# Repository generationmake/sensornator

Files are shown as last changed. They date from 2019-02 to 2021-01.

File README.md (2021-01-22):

# Sensornator
Board with ESP32 in the Arduino Uno form factor

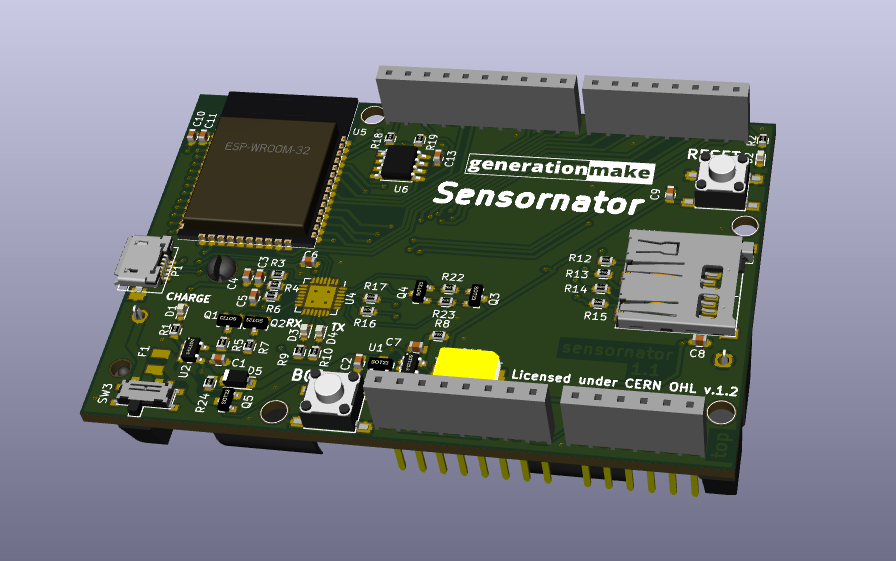
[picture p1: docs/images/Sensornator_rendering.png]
Sensornator rendering


## PCB

### Top

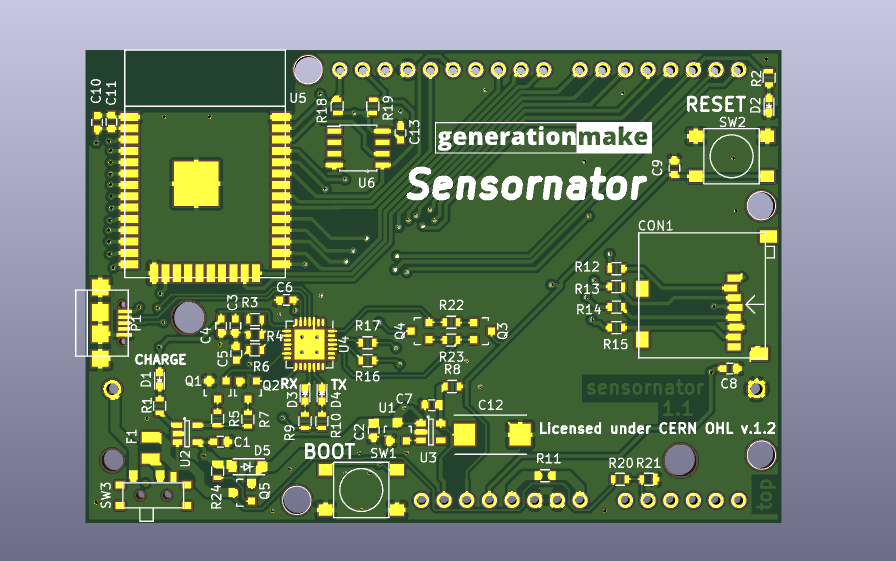
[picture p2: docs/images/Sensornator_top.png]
Sensornator PCB top


### Bottom

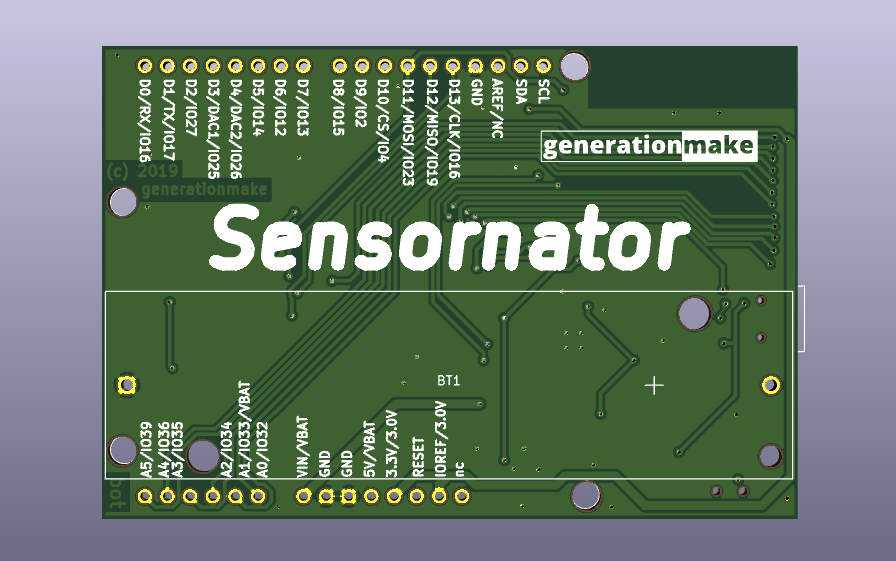
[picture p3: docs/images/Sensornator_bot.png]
Sensornator PCB bot


## License

This hardware is licensed under the CERN OHL v. 1.2

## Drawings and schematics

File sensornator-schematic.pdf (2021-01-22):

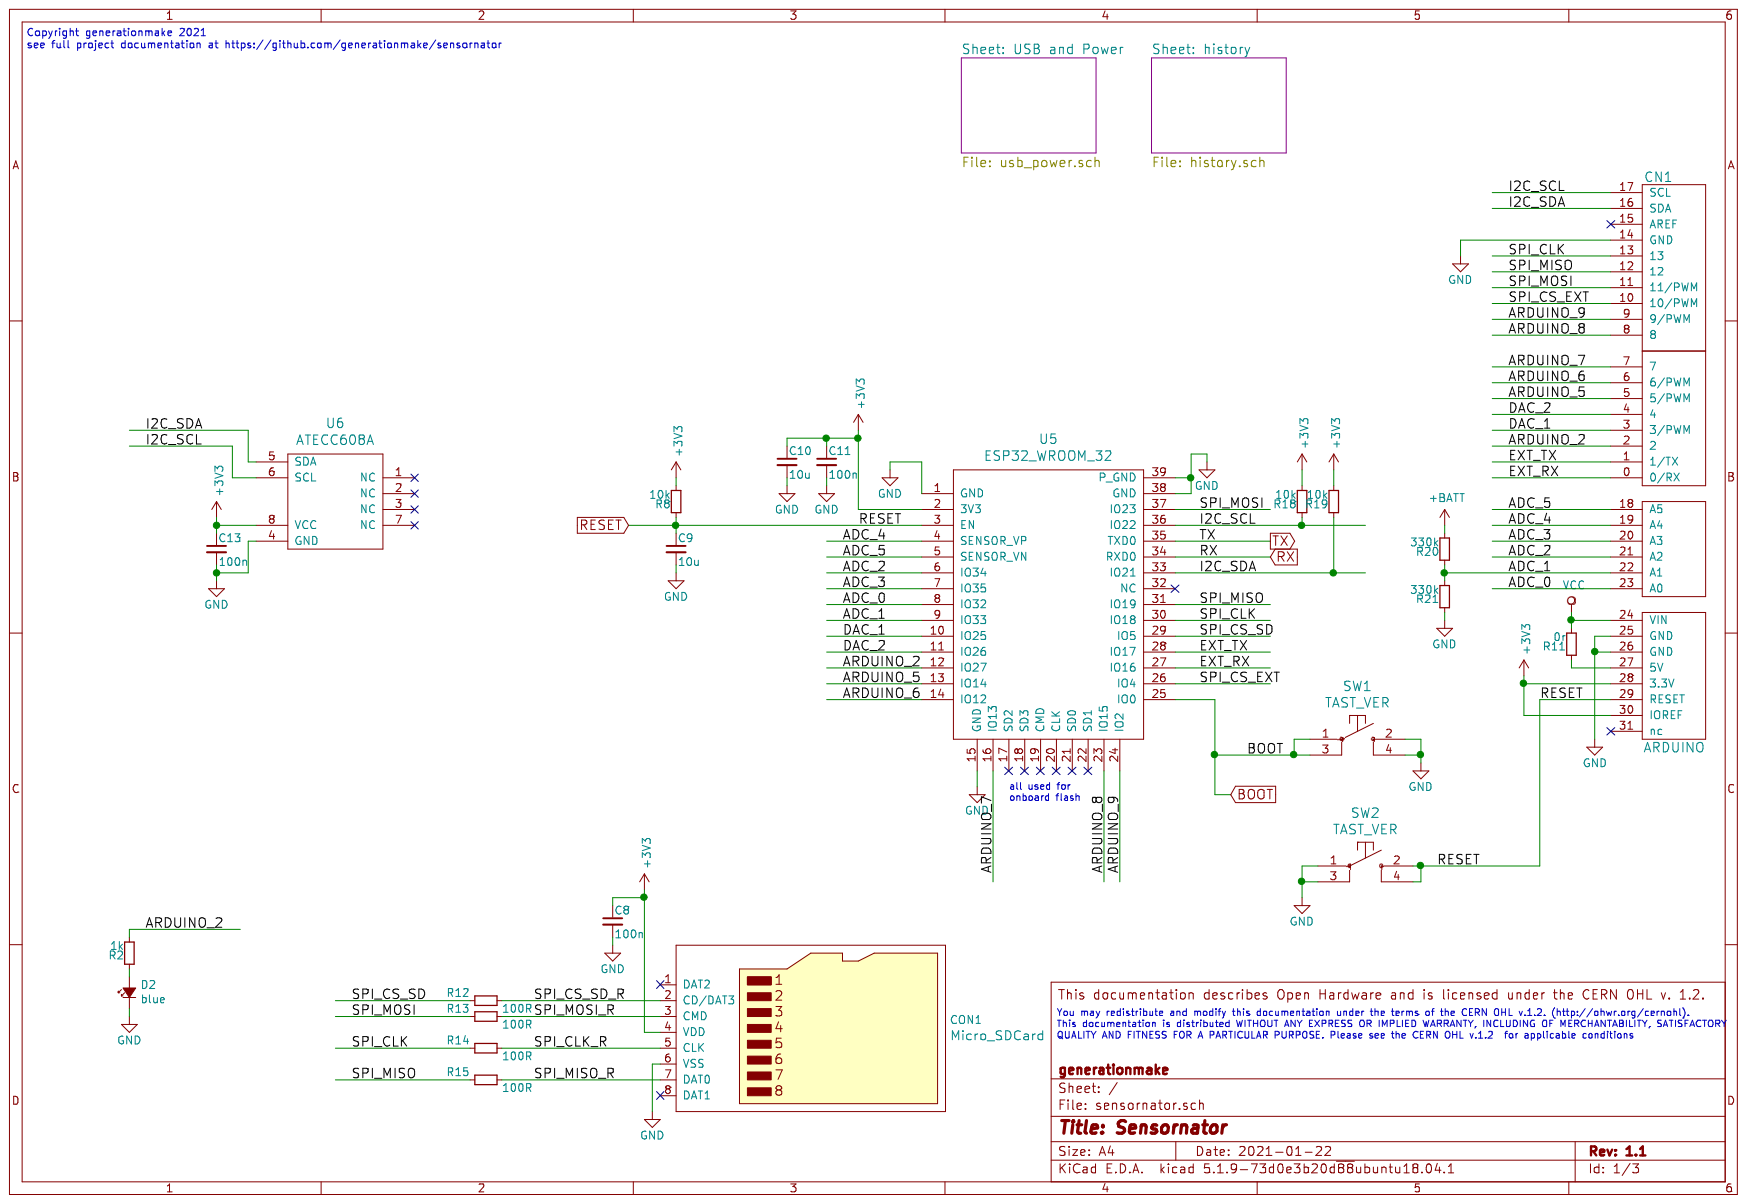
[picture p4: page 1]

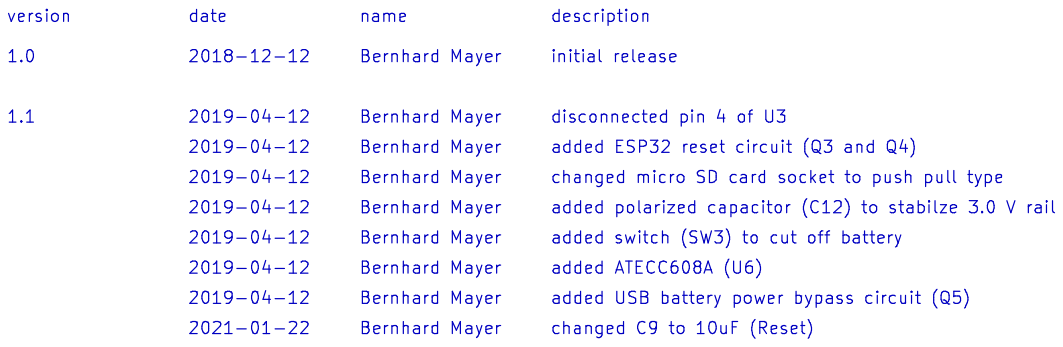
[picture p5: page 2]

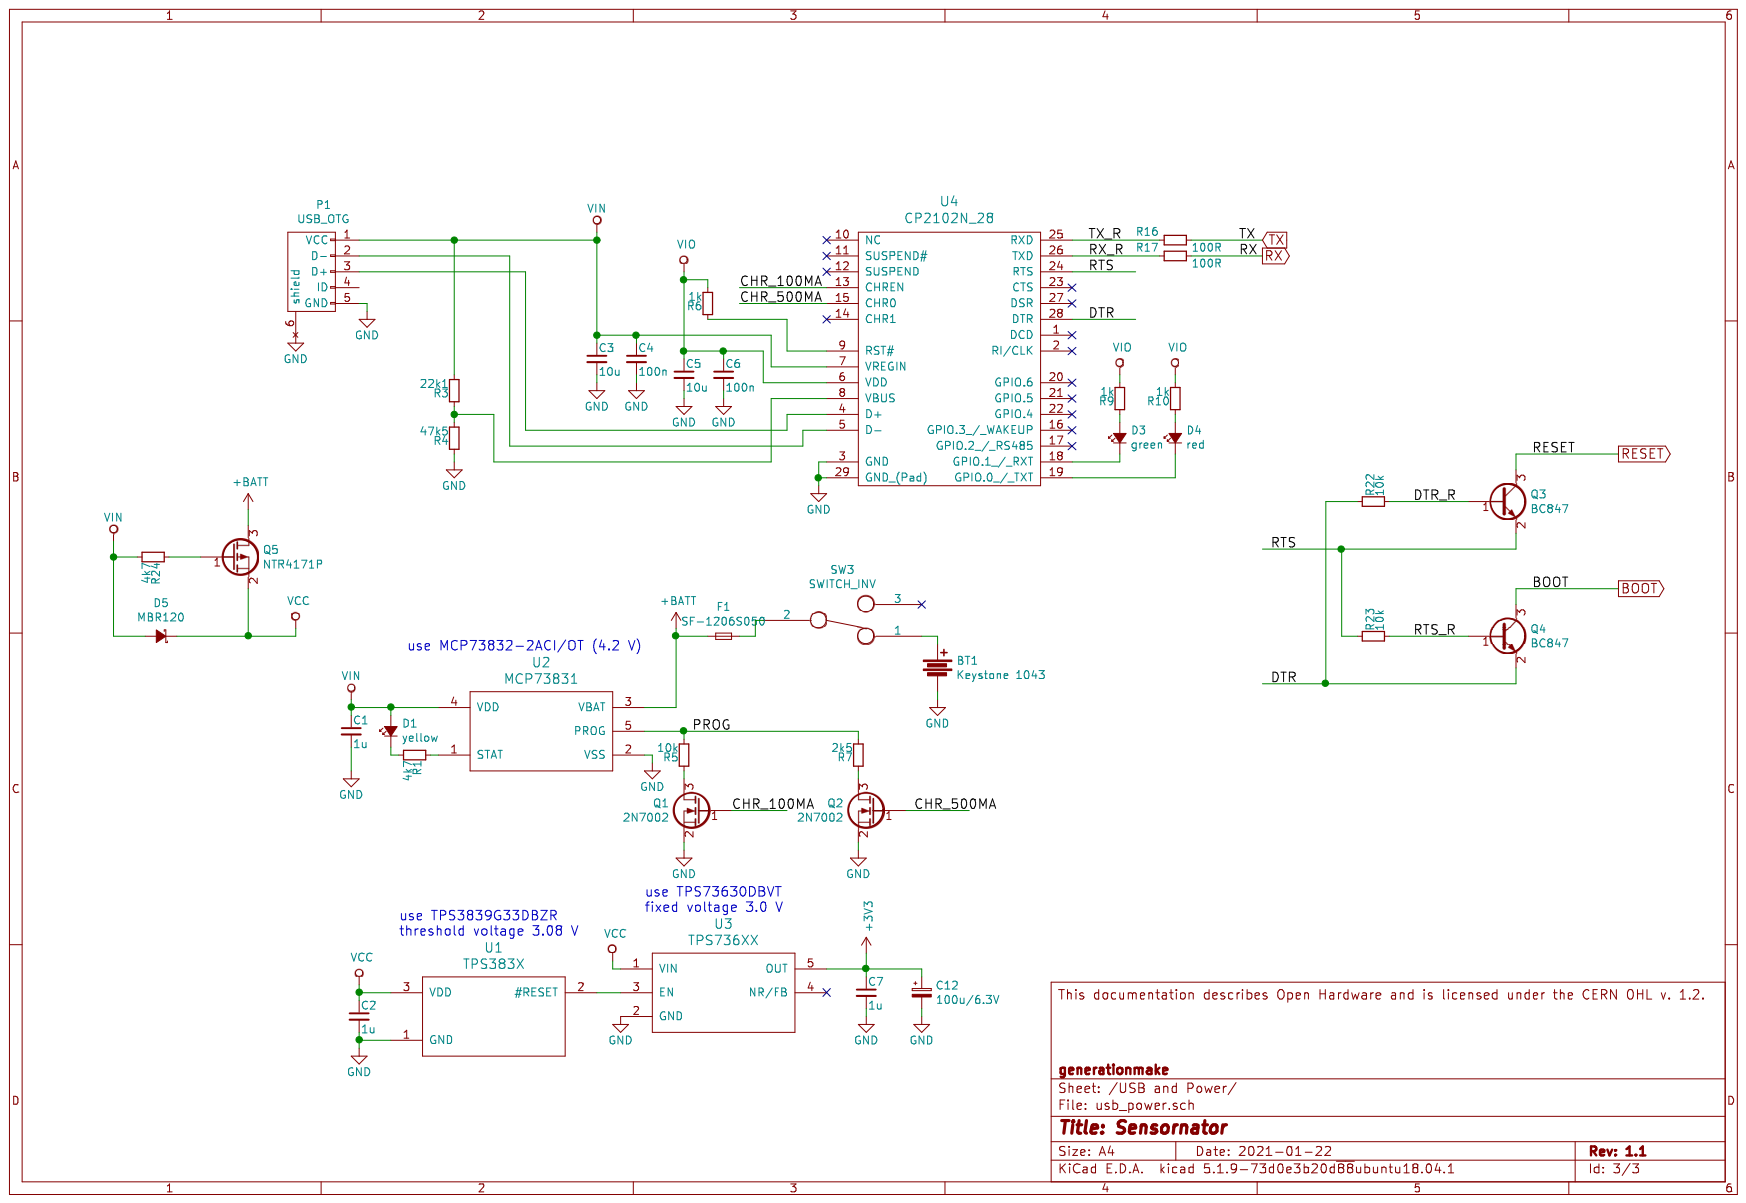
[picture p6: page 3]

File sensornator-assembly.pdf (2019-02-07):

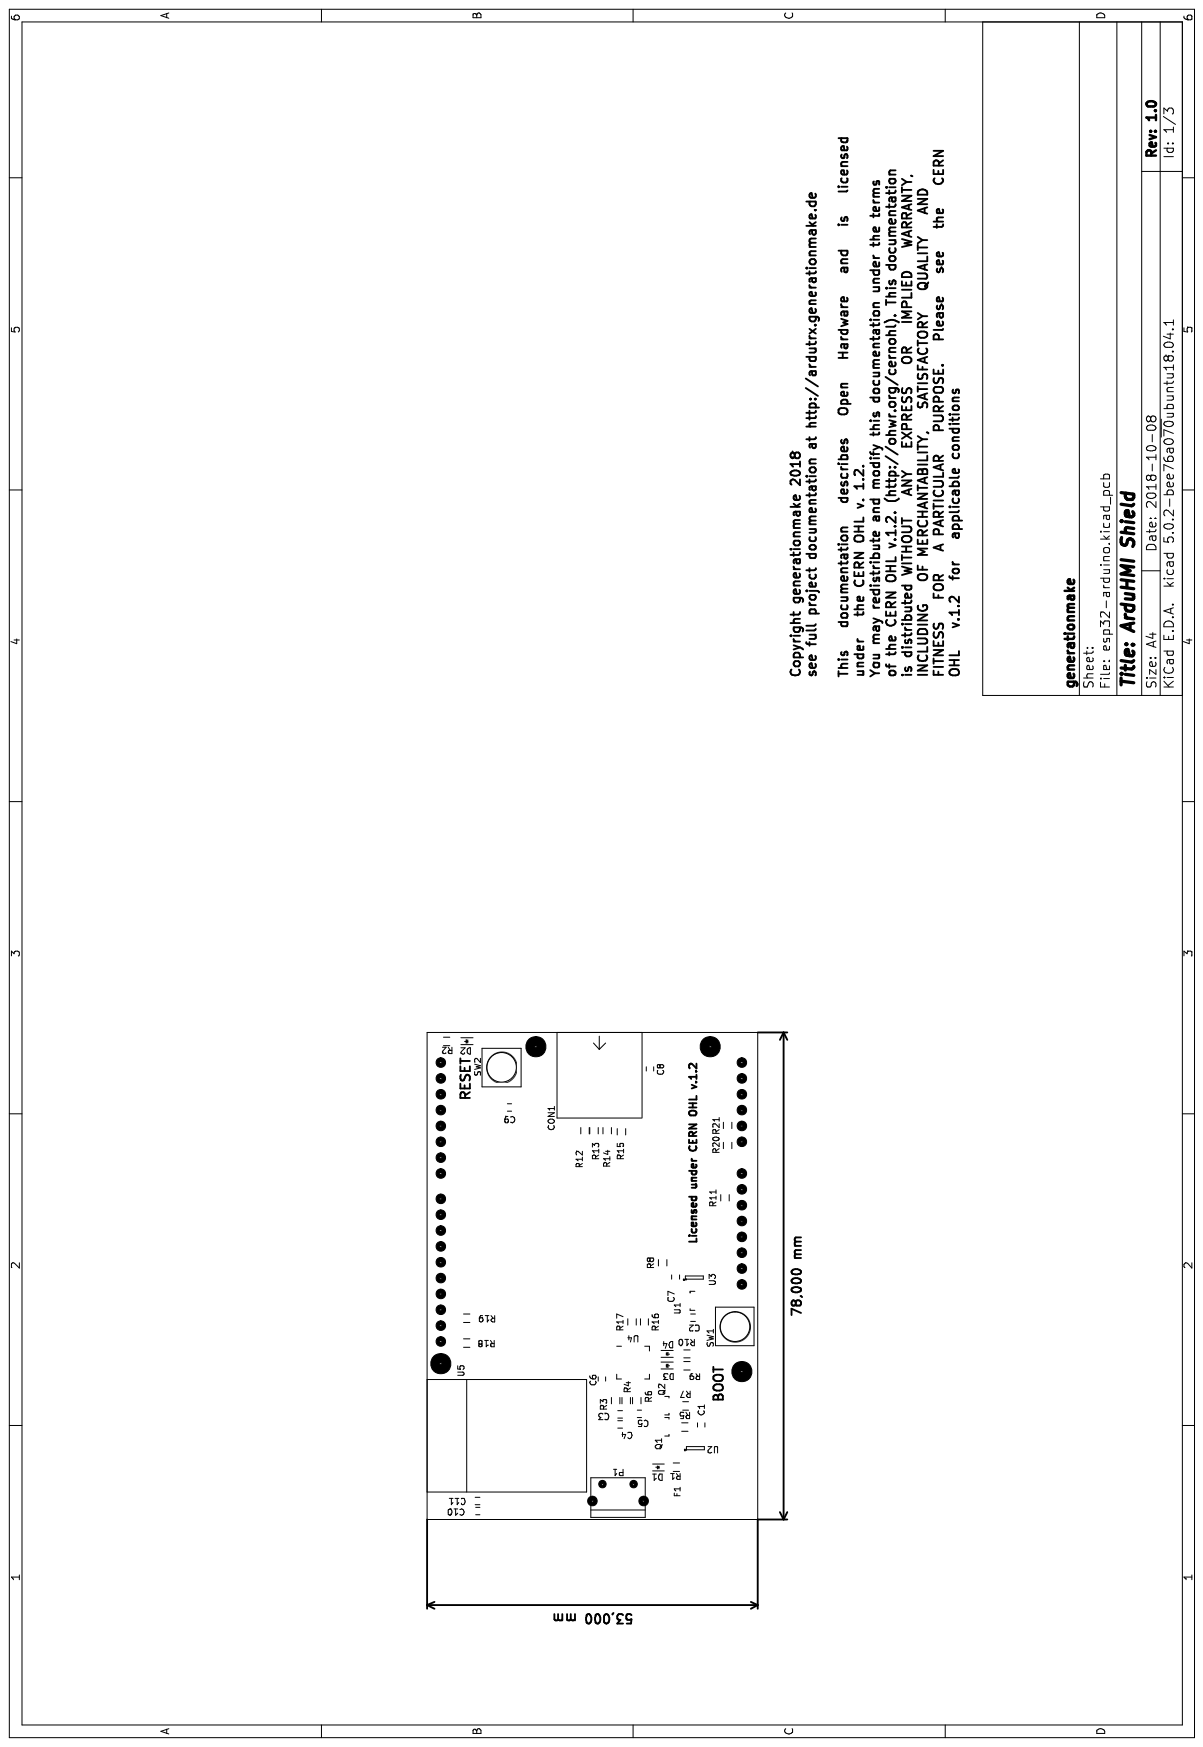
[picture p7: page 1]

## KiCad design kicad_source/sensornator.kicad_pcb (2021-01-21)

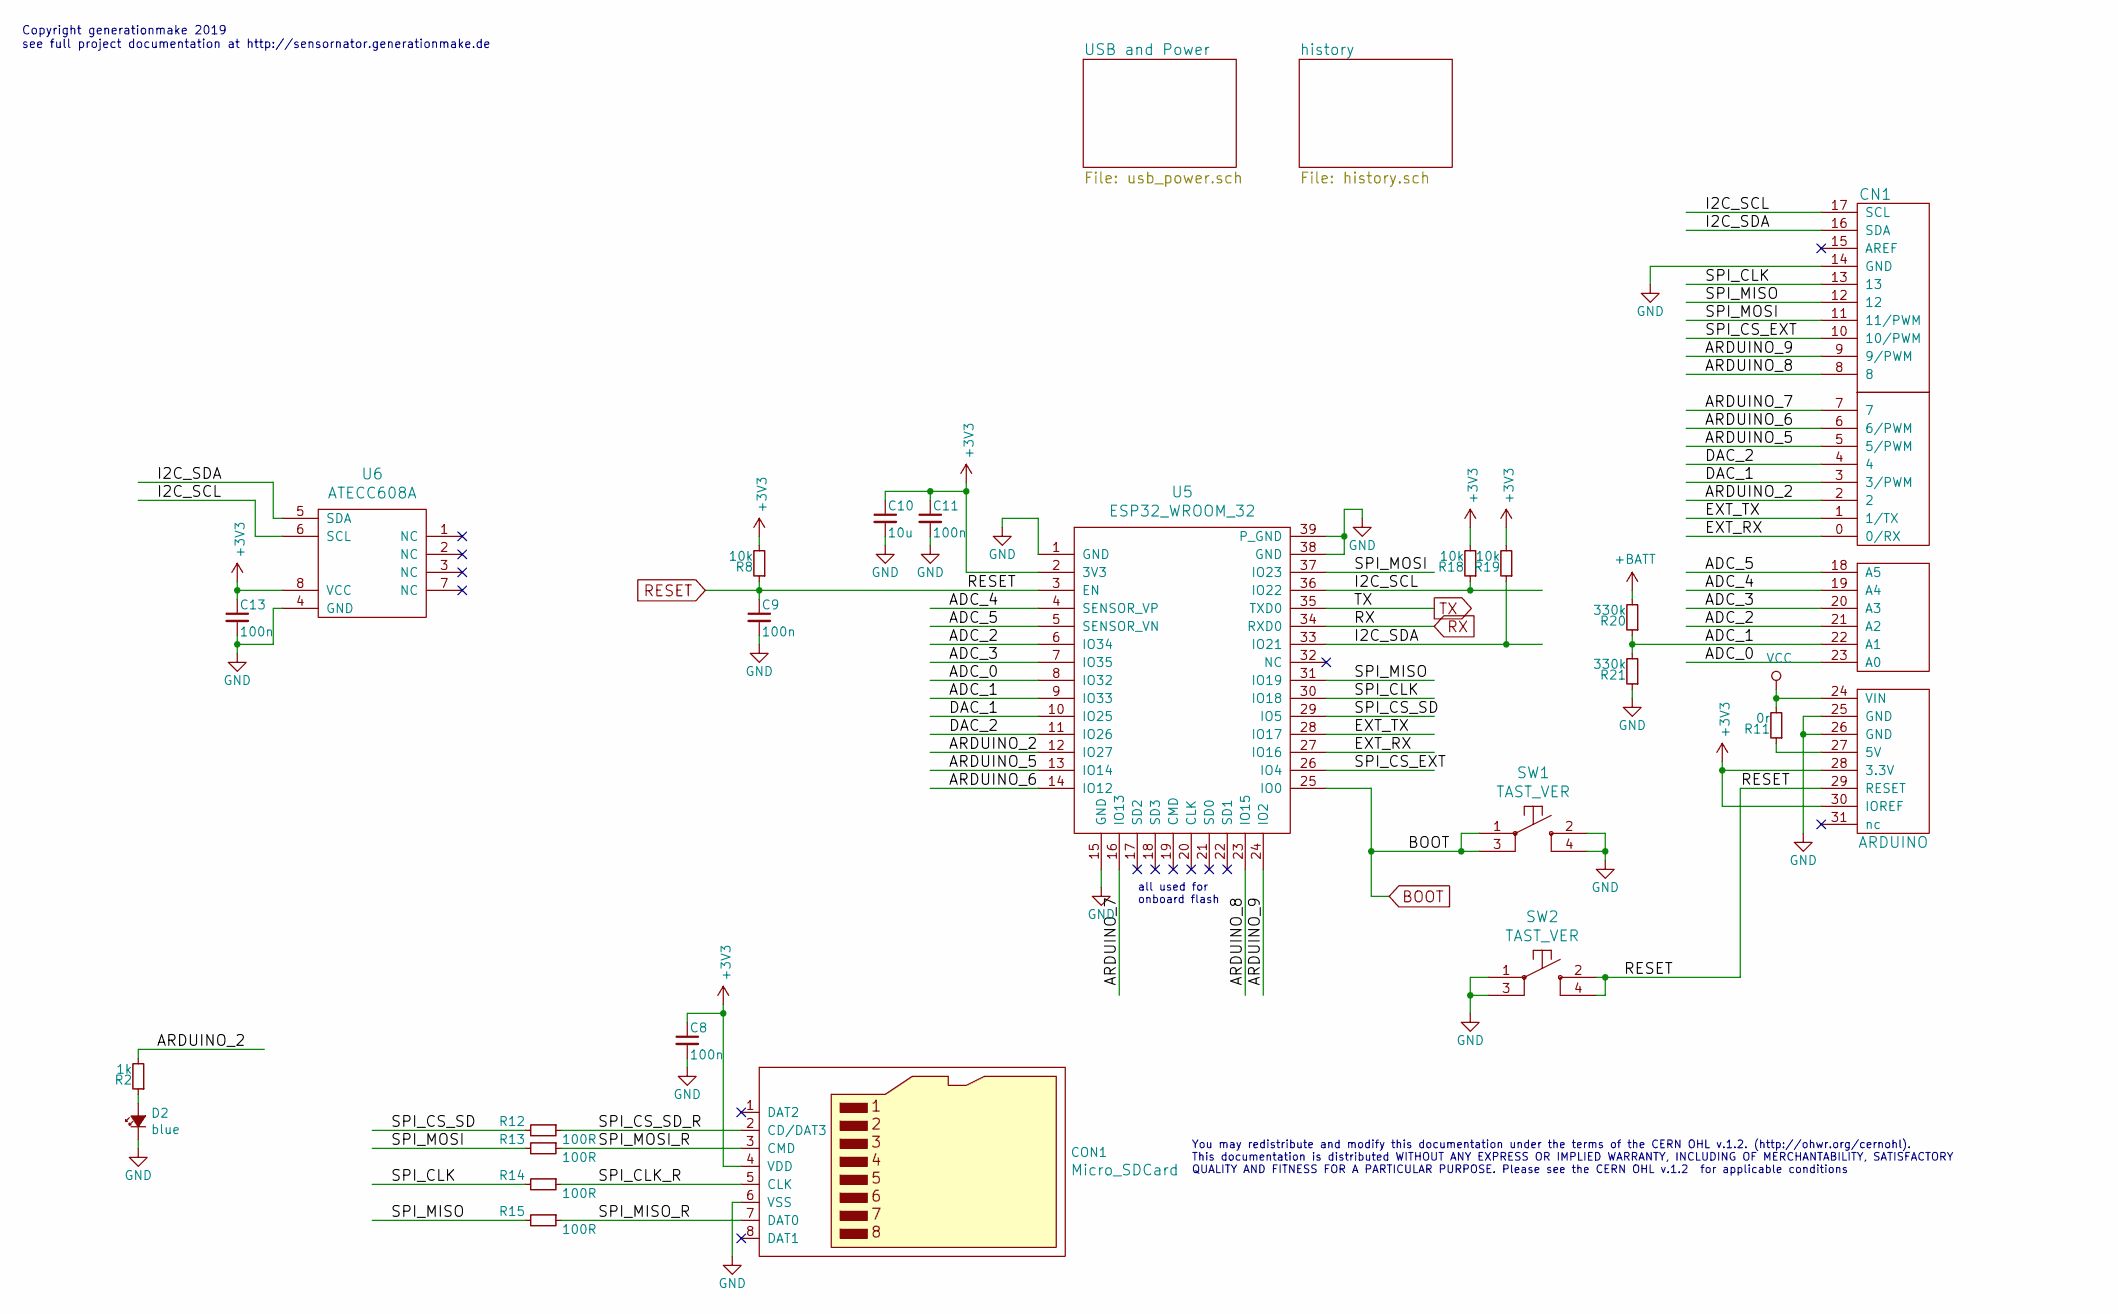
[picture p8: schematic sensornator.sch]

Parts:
C8, C9, C11, C13: 100n; C_0603
C10: 10u; C_0603
CN1: ARDUINO
CON1: Micro_SDCard; WE_693071010811
D2: blue; LED_0603
R2: 1k; R_0603
R8, R18, R19: 10k; R_0603
R11: 0r; R_0603
R12, R13, R14, R15: 100R; R_0603
R20, R21: 330k; R_0603
SW1, SW2: TAST_VER; WE_430182050816
U5: ESP32_WROOM_32; ESP32-WROOM-32
U6: ATECC608A; SOIC-8_3.9x4.9mm_Pitch1.27mm

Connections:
+3V3: C8.1, C10.1, C11.1, C13.1, CN1.28 (3.3V), CN1.30 (IOREF), CON1.4 (VDD), R8.2, R18.2, R19.2, U5.2 (3V3), U6.8 (VCC); also elsewhere on the board
+BATT: R20.2; also elsewhere on the board
/ADC_0: CN1.23 (A0), U5.8 (IO32)
/ADC_1: CN1.22 (A1), R20.1, R21.2, U5.9 (IO33)
/ADC_2: CN1.21 (A2), U5.6 (IO34)
/ADC_3: CN1.20 (A3), U5.7 (IO35)
/ADC_4: CN1.19 (A4), U5.4 (SENSOR_VP)
/ADC_5: CN1.18 (A5), U5.5 (SENSOR_VN)
/ARDUINO_2: CN1.2, R2.2, U5.12 (IO27)
/ARDUINO_5: CN1.5 (5/PWM), U5.13 (IO14)
/ARDUINO_6: CN1.6 (6/PWM), U5.14 (IO12)
/ARDUINO_7: CN1.7, U5.16 (IO13)
/ARDUINO_8: CN1.8, U5.23 (IO15)
/ARDUINO_9: CN1.9 (9/PWM), U5.24 (IO2)
/DAC_1: CN1.3 (3/PWM), U5.10 (IO25)
/DAC_2: CN1.4, U5.11 (IO26)
/EXT_RX: CN1.0 (0/RX), U5.27 (IO16)
/EXT_TX: CN1.1 (1/TX), U5.28 (IO17)
/I2C_SCL: CN1.17 (SCL), R18.1, U5.36 (IO22), U6.6 (SCL)
/I2C_SDA: CN1.16 (SDA), R19.1, U5.33 (IO21), U6.5 (SDA)
/SPI_CLK: CN1.13, R14.2, U5.30 (IO18)
/SPI_CLK_R: CON1.5 (CLK), R14.1
/SPI_CS_EXT: CN1.10 (10/PWM), U5.26 (IO4)
/SPI_CS_SD: R12.2, U5.29 (IO5)
/SPI_CS_SD_R: CON1.2 (CD/DAT3), R12.1
/SPI_MISO: CN1.12, R15.2, U5.31 (IO19)
/SPI_MISO_R: CON1.7 (DAT0), R15.1
/SPI_MOSI: CN1.11 (11/PWM), R13.2, U5.37 (IO23)
/SPI_MOSI_R: CON1.3 (CMD), R13.1
BOOT: SW1.1, SW1.3, U5.25 (IO0); also elsewhere on the board
GND: C8.2, C9.2, C10.2, C11.2, C13.2, CN1.14 (GND), CN1.25 (GND), CN1.26 (GND), CON1.6 (VSS), D2.1 (K), R21.1, SW1.2, SW1.4, SW2.1, SW2.3, U5.1 (GND), U5.15 (GND), U5.38 (GND), U5.39 (P_GND), U6.4 (GND); also elsewhere on the board
unnamed: CN1.27 (5V), R11.1
unnamed: D2.2 (A), R2.1
RESET: C9.1, CN1.29 (RESET), R8.1, SW2.2, SW2.4, U5.3 (EN); also elsewhere on the board
RX: U5.34 (RXD0); also elsewhere on the board
TX: U5.35 (TXD0); also elsewhere on the board
VCC: CN1.24 (VIN), R11.2; also elsewhere on the board

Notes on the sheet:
Copyright generationmake 2019 see full project documentation at http://sensornator.generationmake.de
You may redistribute and modify this documentation under the terms of the CERN OHL v.1.2. (http://ohwr.org/cernohl). This documentation is distributed WITHOUT ANY EXPRESS OR IMPLIED WARRANTY, INCLUDING OF MERCHANTABILITY, SATISFACTORY QUALITY AND FITNESS FOR A PARTICULAR PURPOSE. Please see the CER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
all used for onboard flash

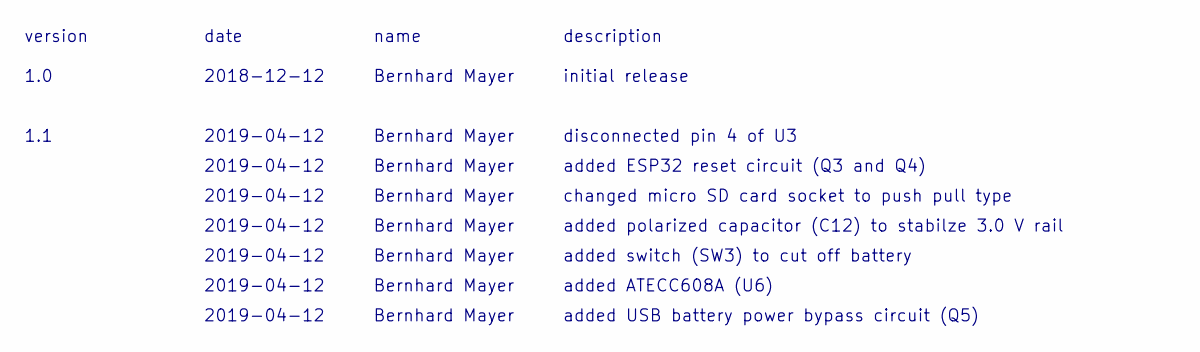
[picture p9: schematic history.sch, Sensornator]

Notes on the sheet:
version
date
name
description
1.0
2018-12-12
Bernhard Mayer
initial release
disconnected pin 4 of U3
2019-04-12
1.1
added ESP32 reset circuit (Q3 and Q4)
changed micro SD card socket to push pull type
added polarized capacitor (C12) to stabilze 3.0 V rail
added switch (SW3) to cut off battery
added ATECC608A (U6)
added USB battery power bypass circuit (Q5)

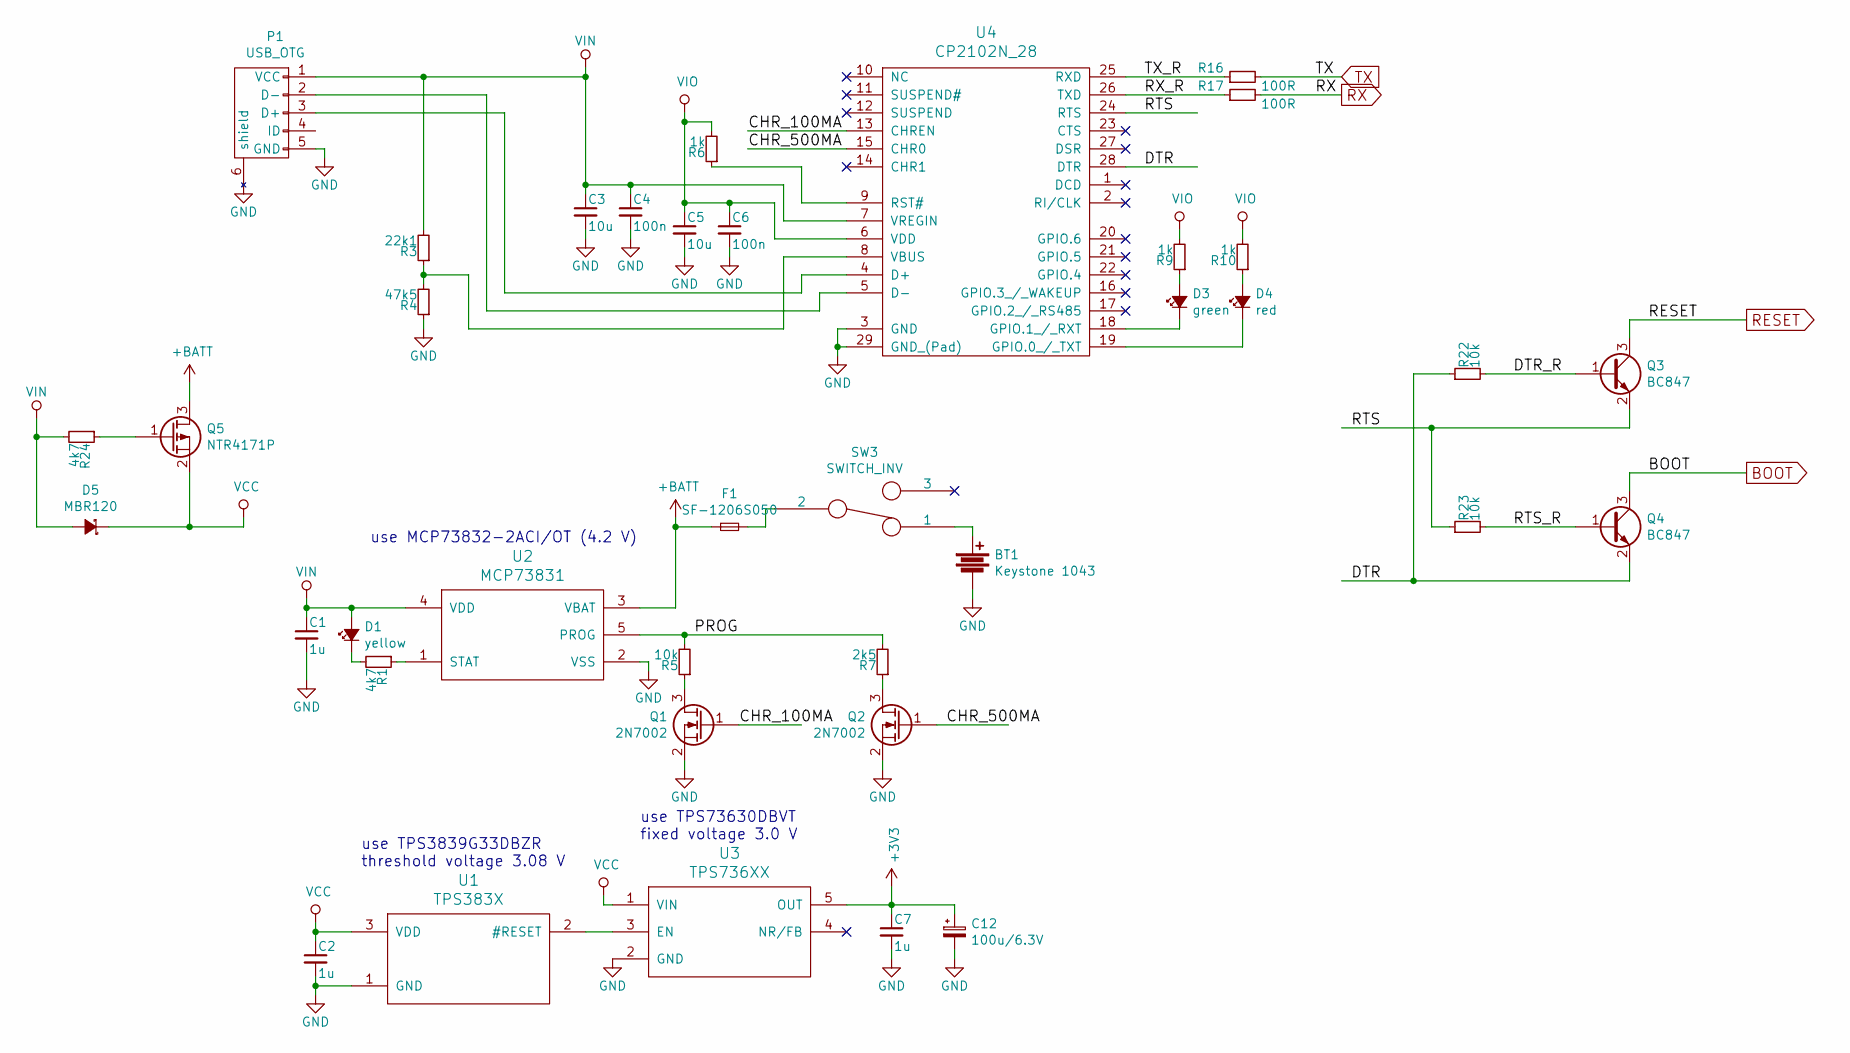
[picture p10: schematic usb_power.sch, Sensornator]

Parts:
BT1: Keystone 1043; KEYSTONE_1043
C1, C2, C7: 1u; C_0603
C3, C5: 10u; C_0603
C4, C6: 100n; C_0603
C12: 100u/6.3V; TantalC_SizeD_EIA-7343_Reflow
D1: yellow; LED_0603
D3: green; LED_0603
D4: red; LED_0603
D5: MBR120; SOD-123
F1: SF-1206S050; Fuse_SMD1206_Reflow
P1: USB_OTG; WE_629105136821
Q1, Q2: 2N7002; SOT-23
Q3, Q4: BC847; SOT-23
Q5: NTR4171P; SOT-23
R1, R24: 4k7; R_0603
R3: 22k1; R_0603
R4: 47k5; R_0603
R5, R22, R23: 10k; R_0603
R6, R9, R10: 1k; R_0603
R7: 2k5; R_0603
R16, R17: 100R; R_0603
SW3: SWITCH_INV; WE_450404015514
U1: TPS383X; SOT-23
U2: MCP73831; SOT-23-5
U3: TPS736XX; SOT-23-5
U4: CP2102N_28; QFN-28-1EP_5x5mm_Pitch0.5mm

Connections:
+3V3: C7.1, C12.1, U3.5 (OUT); also elsewhere on the board
+BATT: F1.1, Q5.3 (D), U2.3 (VBAT); also elsewhere on the board
/USB and Power/CHR_100MA: Q1.1 (G), U4.13 (CHREN)
/USB and Power/CHR_500MA: Q2.1 (G), U4.15 (CHR0)
/USB and Power/DTR: Q4.2 (E), R22.1, U4.28 (DTR)
/USB and Power/DTR_R: Q3.1 (B), R22.2
/USB and Power/PROG: R5.2, R7.2, U2.5 (PROG)
/USB and Power/RTS: Q3.2 (E), R23.1, U4.24 (RTS)
/USB and Power/RTS_R: Q4.1 (B), R23.2
/USB and Power/RX_R: R17.1, U4.26 (TXD)
/USB and Power/TX_R: R16.1, U4.25 (RXD)
BOOT: Q4.3 (C); also elsewhere on the board
GND: BT1.2, C1.2, C2.2, C3.2, C4.2, C5.2, C6.2, C7.2, C12.2, P1.5 (GND), P1.6 (shield), Q1.2 (S), Q2.2 (S), R4.1, U1.1 (GND), U2.2 (VSS), U3.2 (GND), U4.3 (GND), U4.29 (GND_(Pad)); also elsewhere on the board
unnamed: BT1.1, SW3.1
unnamed: D1.1 (K), R1.2
unnamed: D3.1 (K), U4.18 (GPIO.1_/_RXT)
unnamed: D3.2 (A), R9.1
unnamed: D4.1 (K), U4.19 (GPIO.0_/_TXT)
unnamed: D4.2 (A), R10.1
unnamed: F1.2, SW3.2
unnamed: P1.2 (D-), U4.5 (D-)
unnamed: P1.3 (D+), U4.4 (D+)
unnamed: Q1.3 (D), R5.1
unnamed: Q2.3 (D), R7.1
unnamed: Q5.1 (G), R24.1
unnamed: R1.1, U2.1 (STAT)
unnamed: R3.1, R4.2, U4.8 (VBUS)
unnamed: R6.1, U4.9 (RST#)
unnamed: U1.2 (#RESET), U3.3 (EN)
RESET: Q3.3 (C); also elsewhere on the board
RX: R17.2; also elsewhere on the board
TX: R16.2; also elsewhere on the board
VCC: C2.1, D5.1 (K), Q5.2 (S), U1.3 (VDD), U3.1 (VIN); also elsewhere on the board
VIN: C1.1, C3.1, C4.1, D1.2 (A), D5.2 (A), P1.1 (VCC), R3.2, R24.2, U2.4 (VDD), U4.7 (VREGIN)
VIO: C5.1, C6.1, R6.2, R9.2, R10.2, U4.6 (VDD)

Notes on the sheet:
use MCP73832-2ACI/OT (4.2 V)
use TPS3839G33DBZR threshold voltage 3.08 V
use TPS73630DBVT fixed voltage 3.0 V

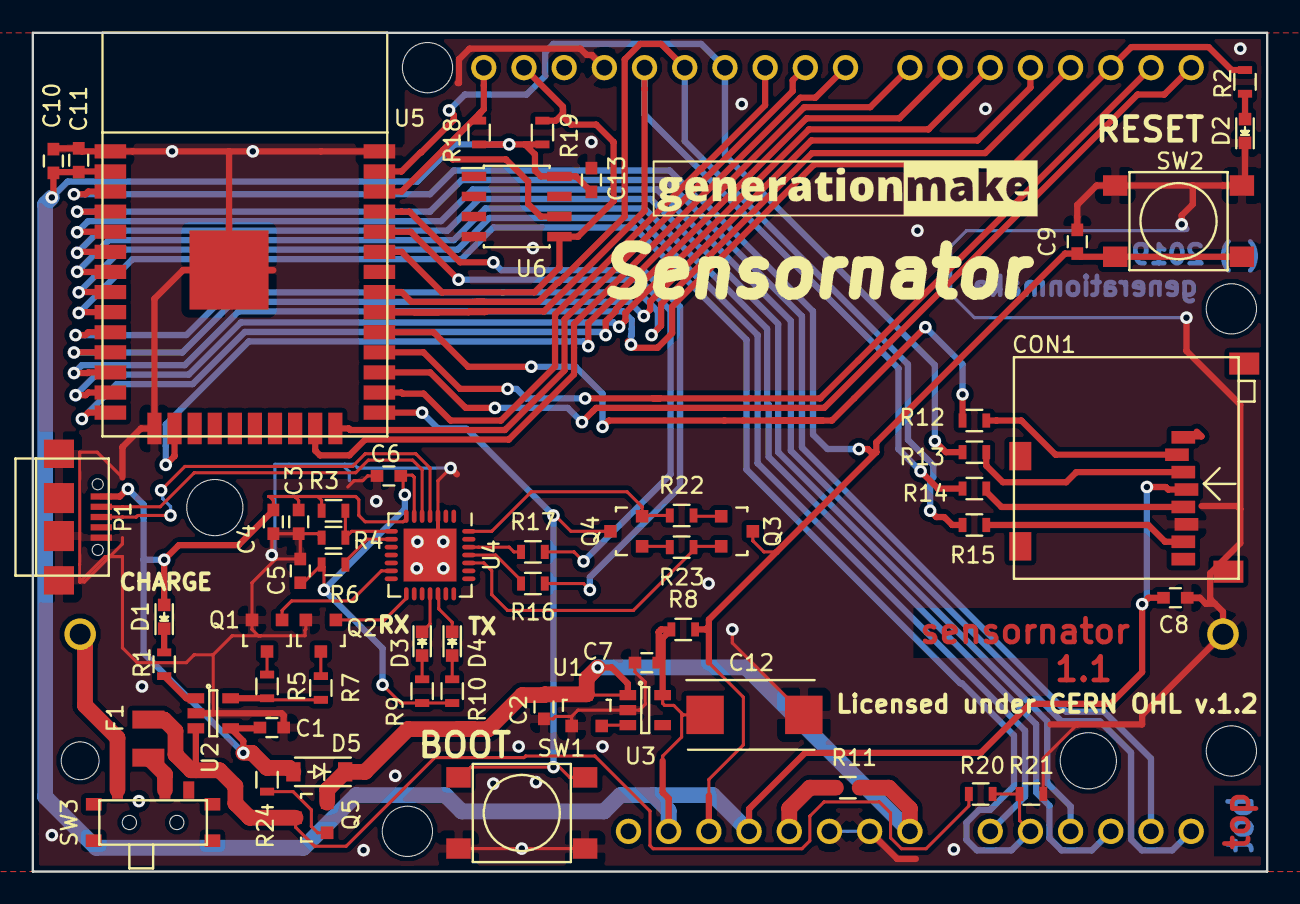
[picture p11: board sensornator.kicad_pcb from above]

Board: 2 copper layers, 78.0 x 53.0 mm, 61 parts (1 on the bottom side), 64 nets.

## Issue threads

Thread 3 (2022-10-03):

add Dronecode CAN connectors

generationmake, 2022-10-03:
to support development of https://github.com/107-systems/107-Arduino-Cyphal

generationmake, 2022-11-01:
RX=IO13 and TX=IO12

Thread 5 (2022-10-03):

add USB C conector

generationmake, 2022-10-03:
will be more common in future and Micro-USB connector didn't fit very well

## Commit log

2018-12-04 added poject files
    [esp32-arduino.kicad_pcb, esp32-arduino.sch]
2018-12-04 corrected library refs
    [esp32-arduino.sch]
2018-12-05 started schematic added ESP32
    [esp32-arduino.kicad_pcb, esp32-arduino.sch]
2018-12-10 added power supply parts, first try for connection with arduino header
    [esp32-arduino.sch]
2018-12-10 corrected schematic, updated layout
    [esp32-arduino.kicad_pcb, esp32-arduino.sch]
2018-12-10 updated pdf schematic
2018-12-11 finished layout, created gerber
    [esp32-arduino-B.Cu.gbl, esp32-arduino-B.Mask.gbs, esp32-arduino-Edge.Cuts.gm1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]
2019-02-07 corrected schematic and layout, generated gerber
    [esp32-arduino-B.Cu.gbl, esp32-arduino-B.Mask.gbs, esp32-arduino-Edge.Cuts.gm1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]
2019-02-10 corrected schematic error at voltage regulator, added resistor values
    [esp32-arduino.sch]
2019-02-17 added some comments, updated some values
    [esp32-arduino.sch]
2019-03-19 added some values in schemtaic
    [esp32-arduino.sch]
2019-03-19 updated netlist and layout
    [esp32-arduino.kicad_pcb]
2019-04-12 renamed files to sensornator
    [sensornator-B.Cu.gbl, sensornator-B.Mask.gbs, sensornator-Edge.Cuts.gm1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]
2019-04-12 renamed folder to sensornator
    [sensornator-B.Cu.gbl, sensornator-B.Mask.gbs, sensornator-Edge.Cuts.gm1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]
2019-04-12 updated schematic, added extra pages for history and usb, added esp32 reset circuit
    [esp32-arduino-B.Cu.gbl, esp32-arduino-B.Mask.gbs, esp32-arduino-Edge.Cuts.gm1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]
2019-04-12 changed micro SD card socket to push pull type, updated footprint of micro USB socket
    [history.sch, sensornator.kicad_pcb, sensornator.sch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]
2019-04-12 updated schematic, added USB voltage bypass, finished layout, corrected 3D models
    [history.sch, sensornator.kicad_pcb, sensornator.sch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]
2019-04-12 added silk screen on back side, updated parameters, generated pdf schematic
    [history.sch, sensornator.kicad_pcb, sensornator.sch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]
2019-04-12 added some part values
    [usb_power.sch]
2021-01-21 moved files to correct folder
    [history.sch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]
2021-01-22 updated to latest KiCAD version
    [history.sch, sensornator.sch, usb_power.sch]
2021-01-22 changed C9 to 10u (reset), updated schematic pdf
    [history.sch, sensornator.sch, usb_power.sch]

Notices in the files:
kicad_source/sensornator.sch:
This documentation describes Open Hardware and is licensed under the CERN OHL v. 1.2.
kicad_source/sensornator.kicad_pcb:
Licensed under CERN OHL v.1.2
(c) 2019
